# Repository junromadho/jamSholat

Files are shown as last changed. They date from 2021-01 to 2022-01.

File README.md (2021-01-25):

# jamSholat
بسم الله الرحمن الرحيم  

Project jam sholat untuk led modul P4.75 dengan menggunakan board berbasis STM32, free to share!

Note: 
Project ini didedikasikan sepenuhnya untuk keperluan amal, silakan memanfaatkan, menyebarkan, dan mengembangkannya. 
Adapun jika anda berniat untuk memanfaatkannya untuk keperluan komersial, harap sisihkan keuntungannya untuk pengembangan lebih lanjut lalu sebarkan ulang pengetahuan tersebut, semoga saja keuntungan yang didapat tidak berhenti hingga rupiah yang terkumpul. tetapi ada keuntungan akhirat yang juga ikut kita tabung.. 

Project ini terdiri dari 3 bagian hardware, software, dan tools
***
## Hardware
Mikrokontroller core yang dipakai adalah varian dari STM32 Bluepill atau Blackpill(belom tested).
Saya biasa memakai varian STM32F103C8T6 dengan papan berwarna biru. 
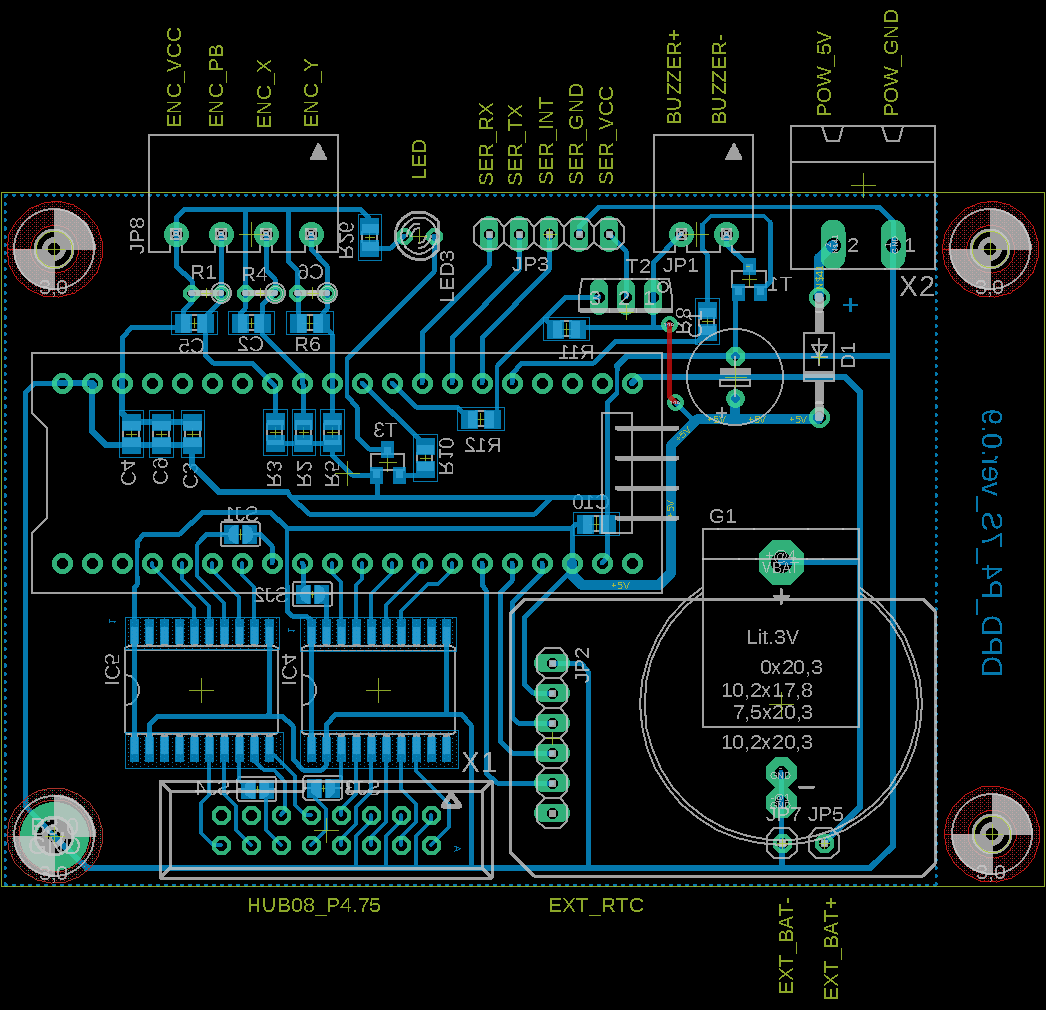
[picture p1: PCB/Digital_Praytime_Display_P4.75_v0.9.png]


Dalam kontroler board utama (file: Digital_Praytime_Display_P4.75_v0.9.brd) terdiri dari:
* soket mikrokontroler
* soket untuk HUB08
* soket baterai RTC 
* interface untuk rotary encoder
* interface untuk serial
* interface untuk buzzer
* terminal power

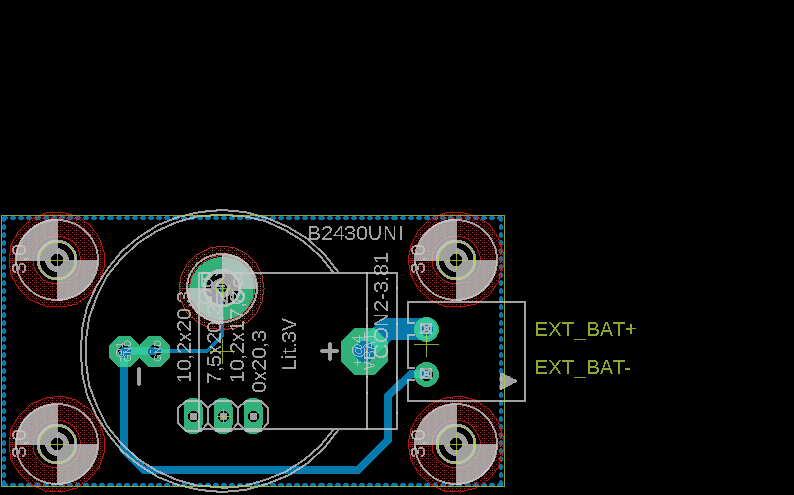
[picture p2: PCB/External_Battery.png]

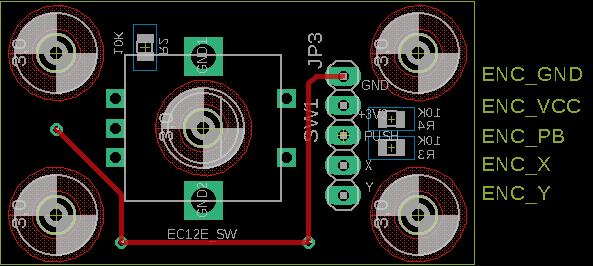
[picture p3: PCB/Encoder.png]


Pada board eksternal (file: External_Battery.brd dan Encoder.brd) terdiri dari:
* soket baterai 
* tombol rotary encoder

board eksternal berfungsi sebagai papan expansi untuk jam sholat yang menggunakan frame tertutup, sehingga board ini bisa diakses diluar 

## Software
Software yang dipakai adalah arduino dengan menggunakan tambahan *hardware* STM32 dari [Arduino STM32](https://github.com/rogerclarkmelbourne/Arduino_STM32). Untuk library saya memakai HUB08 dan RTClock.

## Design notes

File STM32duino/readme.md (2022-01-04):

Di sini semua code untuk STM32F103 arduino

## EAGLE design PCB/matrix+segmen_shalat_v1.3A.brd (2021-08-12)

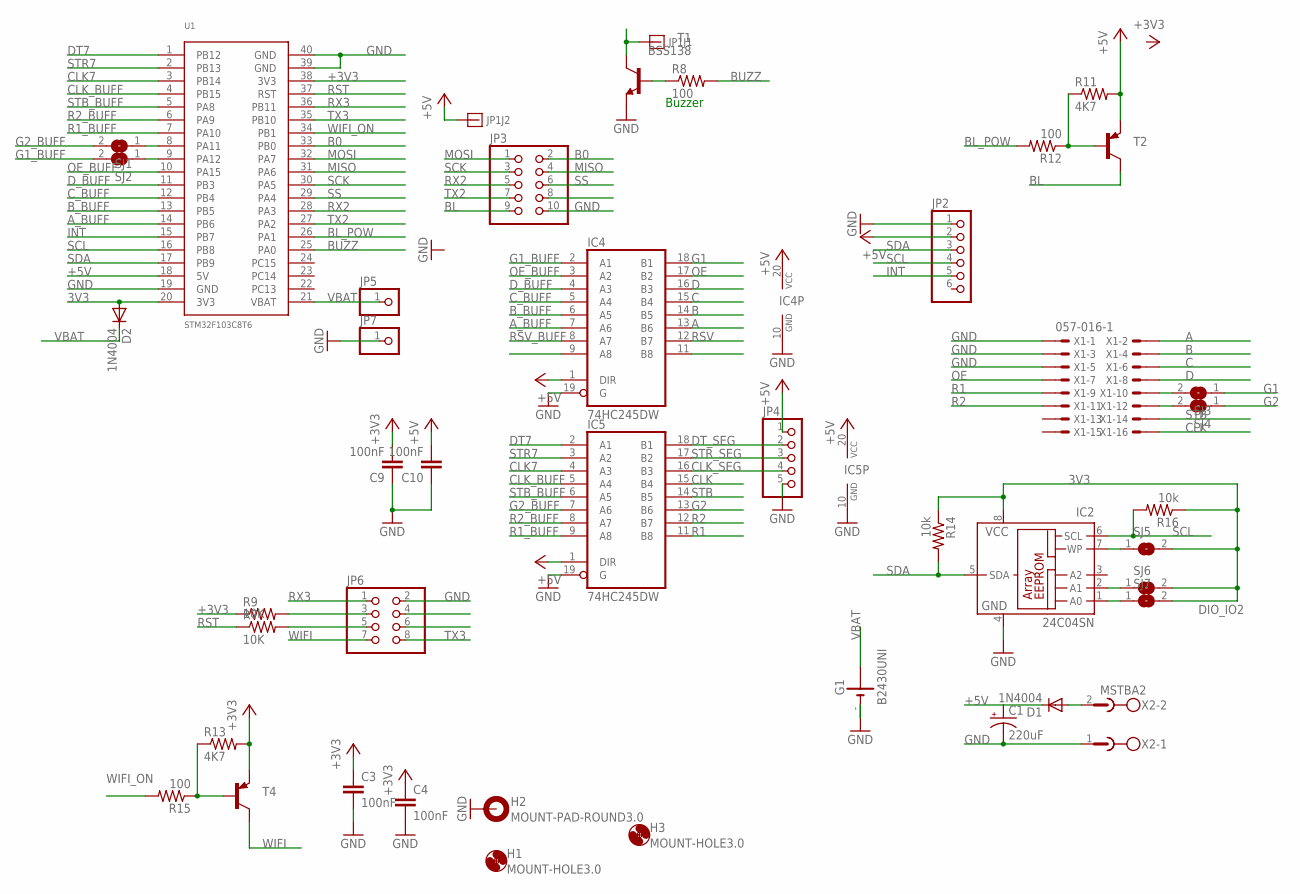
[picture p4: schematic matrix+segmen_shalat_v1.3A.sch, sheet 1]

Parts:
C1: 220uF; E3,5-8
C3, C4, C9, C10: 100nF; C0805
D1, D2: 1N4004; DO41-10
G1: B2430UNI
H1, H3: MOUNT-HOLE3.0; 3,0
H2: MOUNT-PAD-ROUND3.0; 3,0-PAD
IC2: 24C04SN; SO-08
IC4, IC5: 74HC245DW; SO20W
JP1: CON2-3.81
JP2: PINHD-1X6; 1X06
JP3: PINHD-2X5; 2X05
JP4: PINHD-1X5; 1X05
JP5, JP7: PINHD-1X1; 1X01
JP6: PINHD-2X4; 2X04
R7, R9: 10K; R0805
R8, R12, R15: 100; R0805
R11, R13: 4K7; R0805
R14, R16: 10k; R0805
SJ1, SJ2, SJ3, SJ4, SJ5, SJ6, SJ7: SJ
T1: BSS138; SOT23-BEC
T2, T4: -PNP-TO126V; TO126V
U1: STM32F103C8T6; STM32F103
X1: 057-016-1
X2: MSTBA2

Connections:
3V3: D2.A, IC2.8 (VCC), R14.1, R16.1, SJ5.2, SJ6.2, SJ7.2, U1.20 (3V3)
+3V3: C3.1, C4.1, C9.2, R9.1, R13.2, T4.1 (E), U1.38 (3V3)
+5V: C1.+, C10.2, D1.C, IC4.1 (DIR), IC4.20 (VCC), IC5.1 (DIR), IC5.20 (VCC), JP1.2, JP2.2, JP4.1, R11.2, T2.1 (E), U1.18 (5V)
A: IC4.13 (B6), X1.2
A_BUFF: IC4.7 (A6), U1.14 (PB6)
B: IC4.14 (B5), X1.4
B0: JP3.2, U1.33 (PB0)
BL: JP3.9, T2.2 (C)
BL_POW: R12.2, U1.26 (PA1)
BUZZ: R8.2, U1.25 (PA0)
B_BUFF: IC4.6 (A5), U1.13 (PB5)
C: IC4.15 (B4), X1.6
CLK: IC5.15 (B4), X1.16
CLK7: IC5.4 (A3), U1.3 (PB14)
CLK_BUFF: IC5.5 (A4), U1.4 (PB15)
CLK_SEG: IC5.16 (B3), JP4.4
C_BUFF: IC4.5 (A4), U1.12 (PB4)
D: IC4.16 (B3), X1.8
DT7: IC5.2 (A1), U1.1 (PB12)
DT_SEG: IC5.18 (B1), JP4.2
D_BUFF: IC4.4 (A3), U1.11 (PB3)
G1: IC4.18 (B1), SJ3.1
G1_BUFF: IC4.2 (A1), SJ2.2
G2: IC5.13 (B6), SJ4.1
G2_BUFF: IC5.7 (A6), SJ1.2
GND: C1.-, C3.2, C4.2, C9.1, C10.1, G1.-, G1.-@1 (-), H2.B3,0, IC2.4 (GND), IC4.10 (GND), IC4.19 (G), IC5.10 (GND), IC5.19 (G), JP2.1, JP3.10, JP4.5, JP6.2, JP7.1, T1.E, U1.19 (GND), U1.39 (GND), U1.40 (GND), X1.1, X1.3, X1.5, X2.1
INT: JP2.5, U1.15 (PB7)
MISO: JP3.4, U1.31 (PA6)
MOSI: JP3.1, U1.32 (PA7)
unnamed: R11.1, R12.1, T2.3 (B)
unnamed: R8.1, T1.B
unnamed: JP1.1, T1.C
unnamed: JP6.3, R9.2
unnamed: IC2.2 (A1), SJ6.1
unnamed: R13.1, R15.1, T4.3 (B)
unnamed: SJ1.1, U1.8 (PA11)
unnamed: SJ2.1, U1.9 (PA12)
unnamed: SJ4.2, X1.12
unnamed: SJ3.2, X1.10
unnamed: IC2.1 (A0), SJ7.1
unnamed: JP6.5, R7.2
unnamed: D1.A, X2.2
unnamed: IC2.7 (WP), SJ5.1
OE: IC4.17 (B2), X1.7
OE_BUFF: IC4.3 (A2), U1.10 (PA15)
R1: IC5.11 (B8), X1.9
R1_BUFF: IC5.9 (A8), U1.7 (PA10)
R2: IC5.12 (B7), X1.11
R2_BUFF: IC5.8 (A7), U1.6 (PA9)
RST: R7.1, U1.37 (RST)
RSV: IC4.12 (B7)
RSV_BUFF: IC4.8 (A7)
RX2: JP3.5, U1.28 (PA3)
RX3: JP6.1, U1.36 (PB11)
SCK: JP3.3, U1.30 (PA5)
SCL: IC2.6 (SCL), JP2.4, R16.2, U1.16 (PB8)
SDA: IC2.5 (SDA), JP2.3, R14.2, U1.17 (PB9)
SS: JP3.6, U1.29 (PA4)
STB: IC5.14 (B5), X1.14
STB_BUFF: IC5.6 (A5), U1.5 (PA8)
STR7: IC5.3 (A2), U1.2 (PB13)
STR_SEG: IC5.17 (B2), JP4.3
TX2: JP3.7, U1.27 (PA2)
TX3: JP6.8, U1.35 (PB10)
VBAT: D2.C, G1.+@4 (+), JP5.1, U1.21 (VBAT)
WIFI: JP6.7, T4.2 (C)
WIFI_ON: R15.2, U1.34 (PB1)

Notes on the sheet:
Buzzer

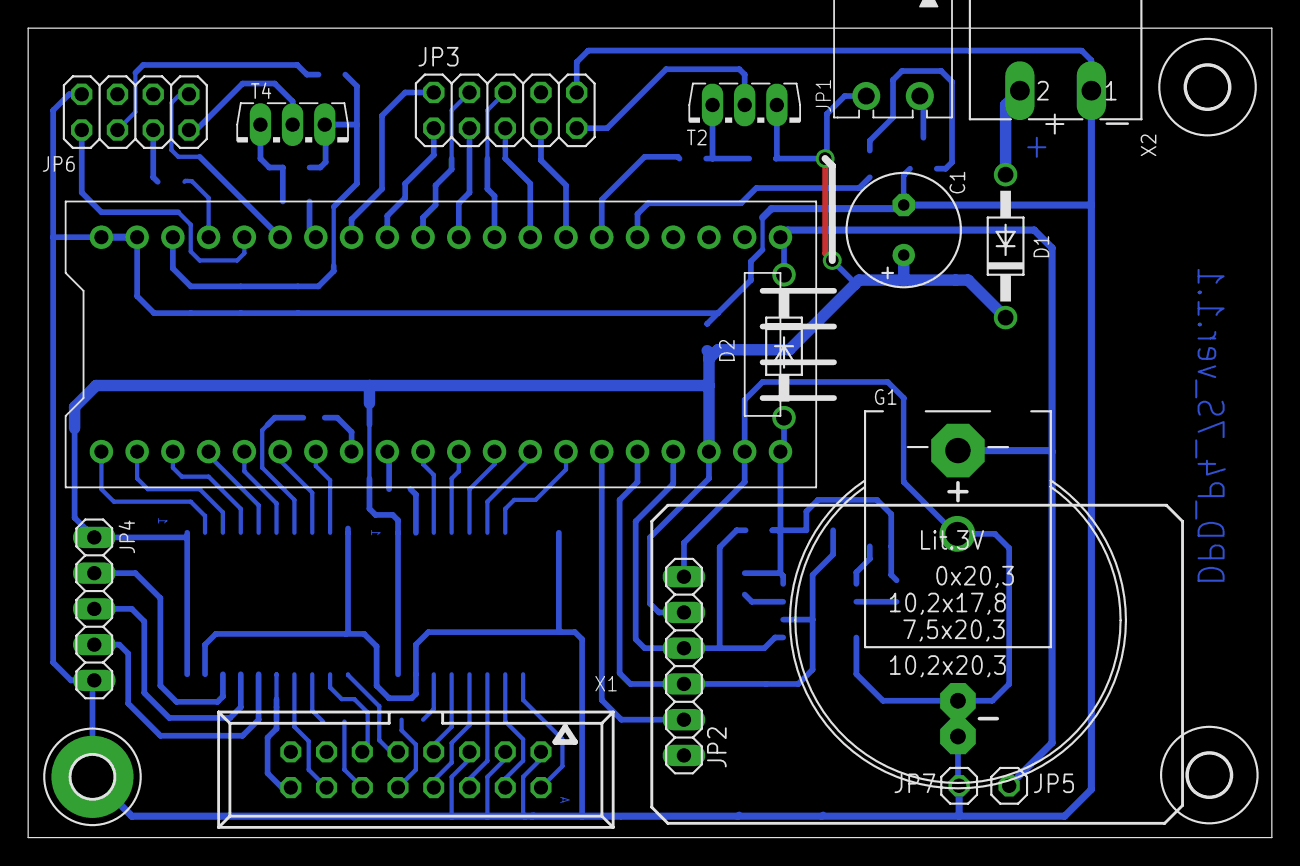
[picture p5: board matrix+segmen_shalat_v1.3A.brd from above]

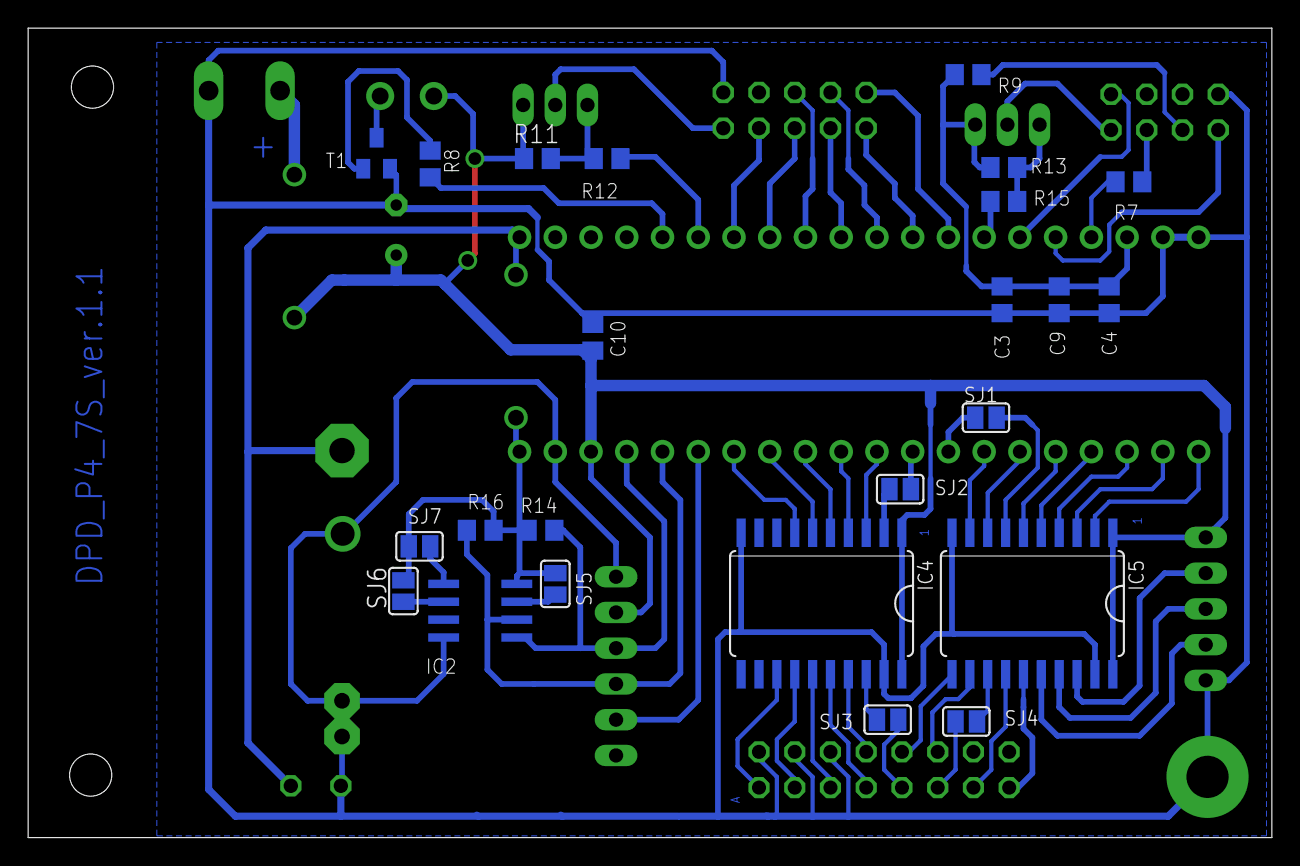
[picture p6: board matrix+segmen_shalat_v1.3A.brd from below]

Board: 2 copper layers, 88.4 x 57.5 mm, 43 parts (24 on the bottom side), 65 nets.

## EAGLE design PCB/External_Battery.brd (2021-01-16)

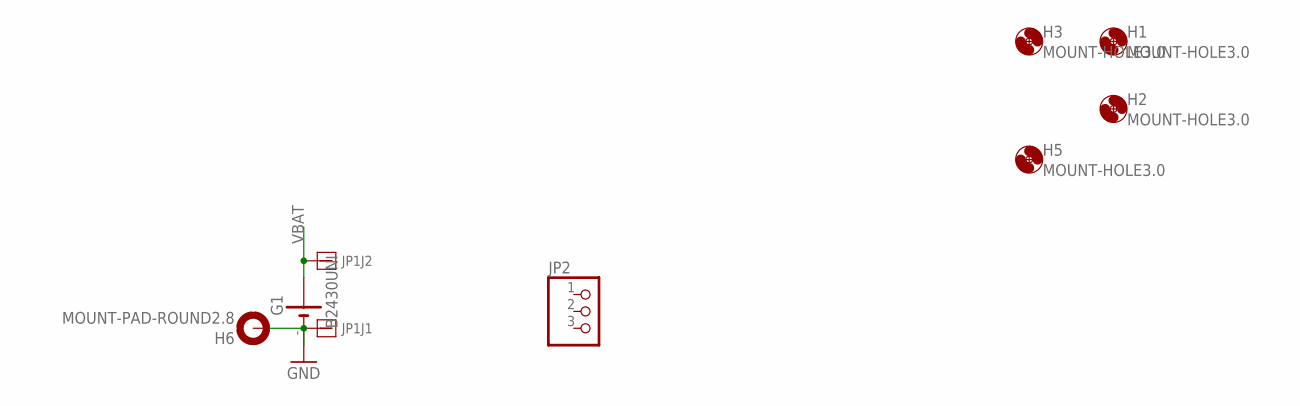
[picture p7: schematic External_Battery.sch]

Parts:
G1: B2430UNI
H1, H2, H3, H5: MOUNT-HOLE3.0; 3,0
H6: MOUNT-PAD-ROUND2.8; 2,8-PAD
JP1: CON2-3.81
JP2: PINHD-1X3; 1X03

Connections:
GND: G1.-, G1.-@1 (-), H6.B2,8, JP1.1
VBAT: G1.+@4 (+), JP1.2

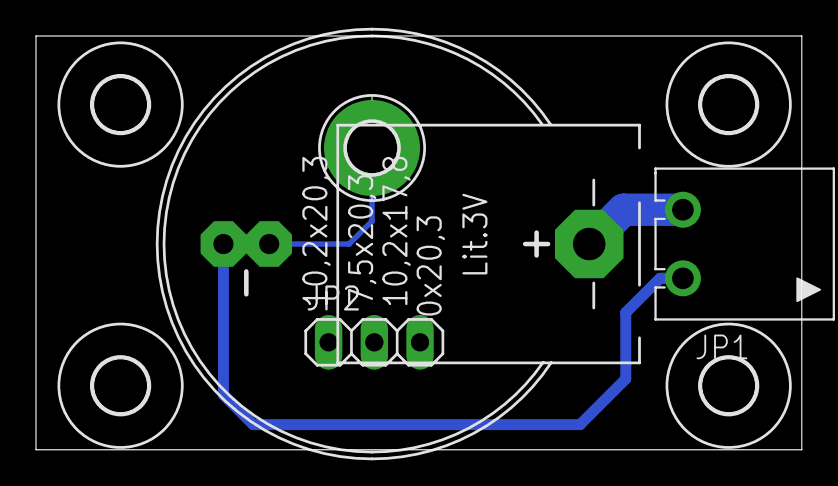
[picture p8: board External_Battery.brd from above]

Board: 2 copper layers, 42.5 x 23.0 mm, 8 parts (0 on the bottom side), 2 nets.

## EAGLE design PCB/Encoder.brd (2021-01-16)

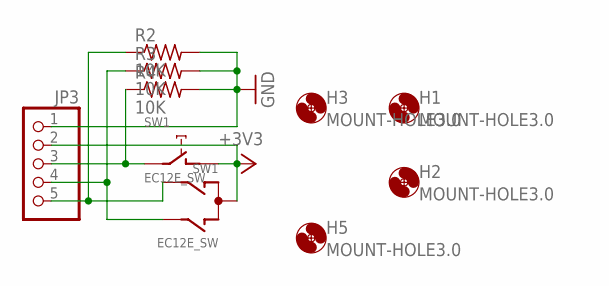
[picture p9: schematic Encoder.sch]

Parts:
H1, H2, H3, H5: MOUNT-HOLE3.0; 3,0
JP3: PINHD-1X5; 1X05
R2, R3, R4: 10K; R0805
SW1: EC12E_SW; ALPS_EC12E_SW

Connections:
+3V3: JP3.2, SW1.C, SW1.D (1)
GND: JP3.1, R2.2, R3.2, R4.2
unnamed: JP3.4, R3.1, SW1.B
unnamed: JP3.5, R2.1, SW1.A
unnamed: JP3.3, R4.1, SW1.E (2)

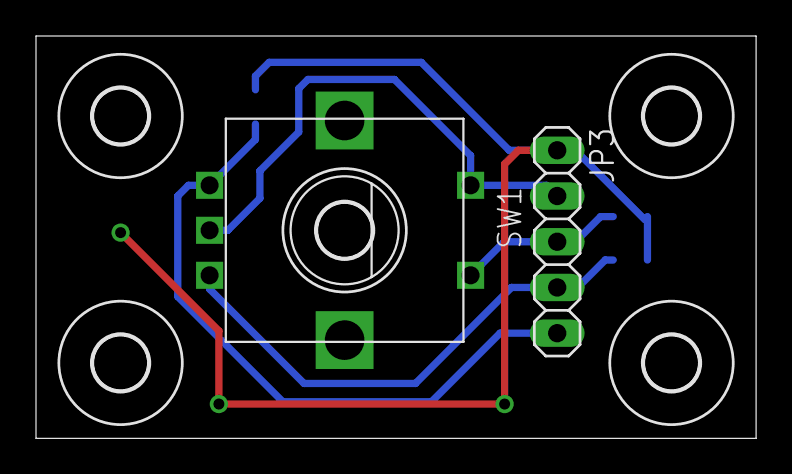
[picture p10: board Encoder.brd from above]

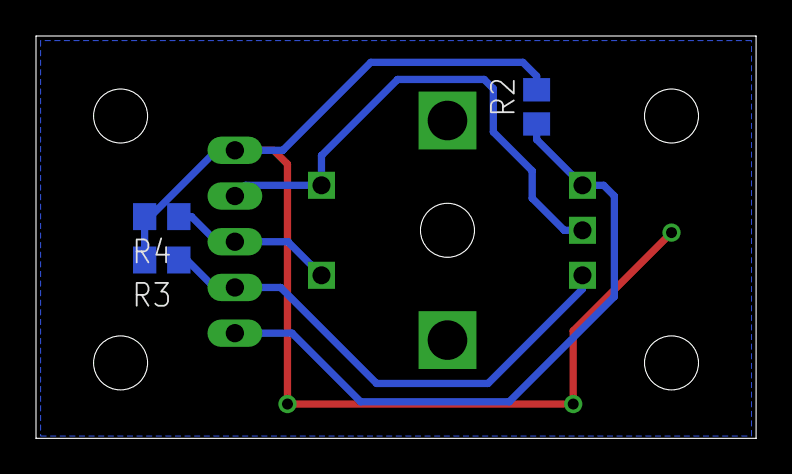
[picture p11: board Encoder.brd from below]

Board: 2 copper layers, 40.0 x 22.4 mm, 10 parts (3 on the bottom side), 5 nets.

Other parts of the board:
H4: MOUNT-HOLE3.0; 3,0

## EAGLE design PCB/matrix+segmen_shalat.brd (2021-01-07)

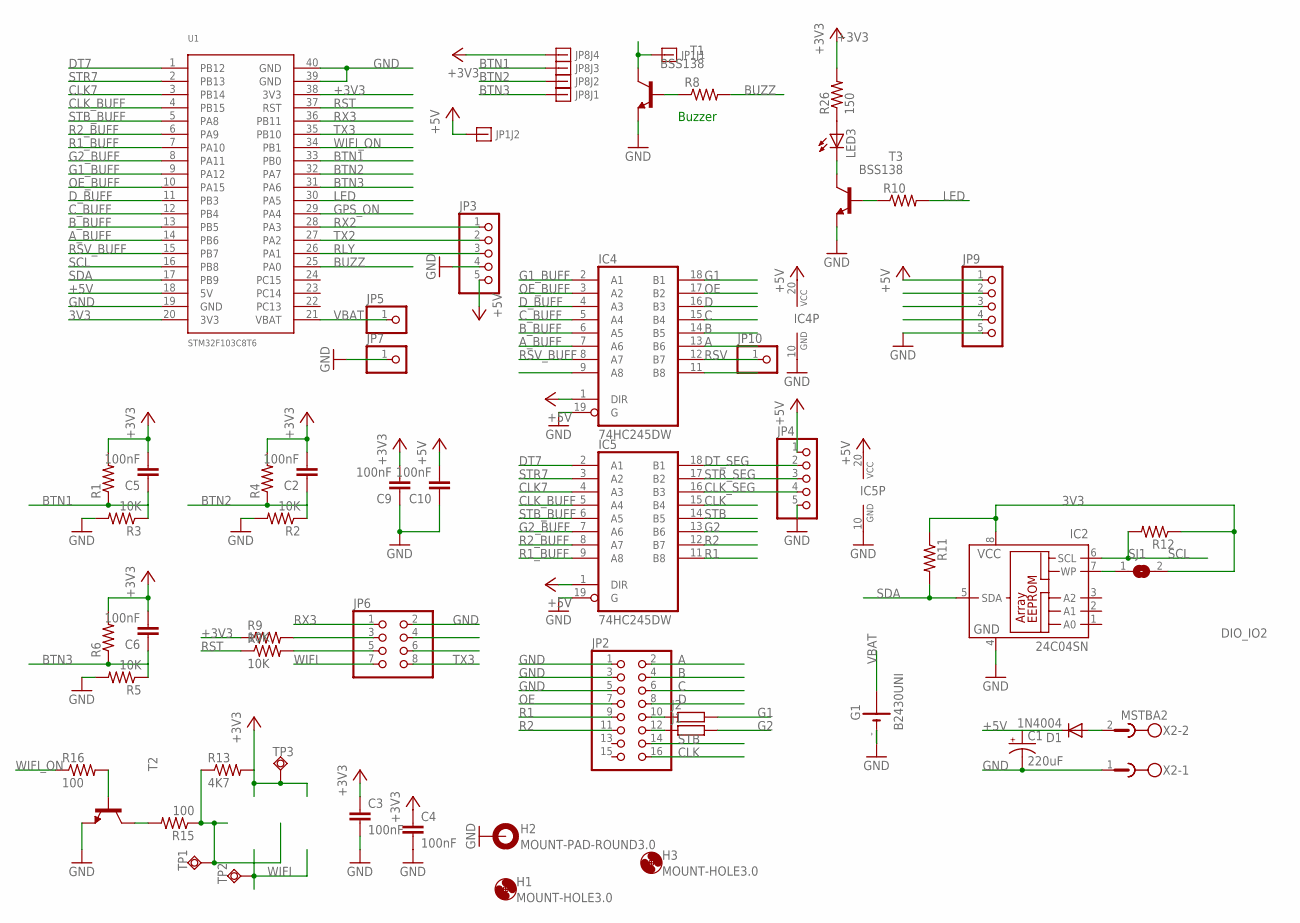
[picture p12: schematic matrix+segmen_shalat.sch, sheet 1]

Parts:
C1: 220uF; E3,5-8
C2, C3, C4, C5, C6, C9, C10: 100nF; C0805
D1: 1N4004; DO41-10
G1: B2430UNI
H1, H3: MOUNT-HOLE3.0; 3,0
H2: MOUNT-PAD-ROUND3.0; 3,0-PAD
IC2: 24C04SN; SO-08
IC4, IC5: 74HC245DW; SO20W
J1, J2: R-EU_R0402; R0402
JP1: CON2-3.81
JP2: PINHD-2X8; 2X08
JP3, JP4, JP9: PINHD-1X5; 1X05
JP5, JP7, JP10: PINHD-1X1; 1X01
JP6: PINHD-2X4; 2X04
JP8: CON4-3.81
LED3: LED3MM
R1, R4, R6: R-US_0204/2V; 0204V
R2, R3, R5: 10K; M0805
R7, R9: 10K; R0805
R8, R10, R11, R12: R-US_R0805; R0805
R13: 4K7; R0805
R15, R16: 100; R0805
R26: 150; R0805
SJ1: SJ
T1, T3: BSS138; SOT23-BEC
T2: MMBT2222ALT1-NPN-SOT23-BEC; SOT23-BEC
TP1, TP2, TP3: TPSQPAD1-13Y; P1-13Y
U1: STM32F103C8T6; STM32F103
X2: MSTBA2

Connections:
3V3: IC2.8 (VCC), R11.1, R12.1, SJ1.2, U1.20 (3V3)
+3V3: C2.2, C3.1, C4.1, C5.2, C6.2, C9.2, JP8.4, R1.2, R4.2, R6.2, R9.1, R13.2, R26.2, TP3.TP, U1.38 (3V3)
+5V: C1.+, C10.2, D1.C, IC4.1 (DIR), IC4.20 (VCC), IC5.1 (DIR), IC5.20 (VCC), JP1.2, JP3.5, JP4.1, JP9.1, U1.18 (5V)
A: IC4.13 (B6), JP2.2
A_BUFF: IC4.7 (A6), U1.14 (PB6)
B: IC4.14 (B5), JP2.4
BTN1: C5.1, JP8.3, R1.1, R3.1, U1.33 (PB0)
BTN2: C2.1, JP8.2, R2.1, R4.1, U1.32 (PA7)
BTN3: C6.1, JP8.1, R5.1, R6.1, U1.31 (PA6)
BUZZ: R8.2, U1.25 (PA0)
B_BUFF: IC4.6 (A5), U1.13 (PB5)
C: IC4.15 (B4), JP2.6
CLK: IC5.15 (B4), JP2.16
CLK7: IC5.4 (A3), U1.3 (PB14)
CLK_BUFF: IC5.5 (A4), U1.4 (PB15)
CLK_SEG: IC5.16 (B3), JP4.4
C_BUFF: IC4.5 (A4), U1.12 (PB4)
D: IC4.16 (B3), JP2.8
DT7: IC5.2 (A1), U1.1 (PB12)
DT_SEG: IC5.18 (B1), JP4.2
D_BUFF: IC4.4 (A3), U1.11 (PB3)
G1: IC4.18 (B1), J2.2
G1_BUFF: IC4.2 (A1), U1.9 (PA12)
G2: IC5.13 (B6), J1.2
G2_BUFF: IC5.7 (A6), U1.8 (PA11)
GND: C1.-, C3.2, C4.2, C9.1, C10.1, G1.-, G1.-@1 (-), H2.B3,0, IC2.4 (GND), IC4.10 (GND), IC4.19 (G), IC5.10 (GND), IC5.19 (G), JP2.1, JP2.3, JP2.5, JP3.4, JP4.5, JP6.2, JP7.1, JP9.5, R2.2, R3.2, R5.2, T1.E, T2.E, T3.E, U1.19 (GND), U1.39 (GND), U1.40 (GND), X2.1
GPS_ON: U1.29 (PA4)
LED: R10.2, U1.30 (PA5)
unnamed: J1.1, JP2.12
unnamed: LED3.K (C), T3.C
unnamed: R10.1, T3.B
unnamed: R8.1, T1.B
unnamed: JP1.1, T1.C
unnamed: JP6.3, R9.2
unnamed: J2.1, JP2.10
unnamed: R13.1, R15.1, TP1.TP
unnamed: R15.2, T2.C
unnamed: JP6.5, R7.2
unnamed: R16.2, T2.B
unnamed: LED3.A, R26.1
unnamed: D1.A, X2.2
unnamed: IC2.7 (WP), SJ1.1
OE: IC4.17 (B2), JP2.7
OE_BUFF: IC4.3 (A2), U1.10 (PA15)
R1: IC5.11 (B8), JP2.9
R1_BUFF: IC5.9 (A8), U1.7 (PA10)
R2: IC5.12 (B7), JP2.11
R2_BUFF: IC5.8 (A7), U1.6 (PA9)
RLY: JP3.3, U1.26 (PA1)
RST: R7.1, U1.37 (RST)
RSV: IC4.12 (B7), JP10.1
RSV_BUFF: IC4.8 (A7), U1.15 (PB7)
RX2: JP3.1, U1.28 (PA3)
RX3: JP6.1, U1.36 (PB11)
SCL: IC2.6 (SCL), R12.2, U1.16 (PB8)
SDA: IC2.5 (SDA), R11.2, U1.17 (PB9)
STB: IC5.14 (B5), JP2.14
STB_BUFF: IC5.6 (A5), U1.5 (PA8)
STR7: IC5.3 (A2), U1.2 (PB13)
STR_SEG: IC5.17 (B2), JP4.3
TX2: JP3.2, U1.27 (PA2)
TX3: JP6.8, U1.35 (PB10)
VBAT: G1.+@4 (+), JP5.1, U1.21 (VBAT)
WIFI: JP6.7, TP2.TP
WIFI_ON: R16.1, U1.34 (PB1)

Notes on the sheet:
Buzzer

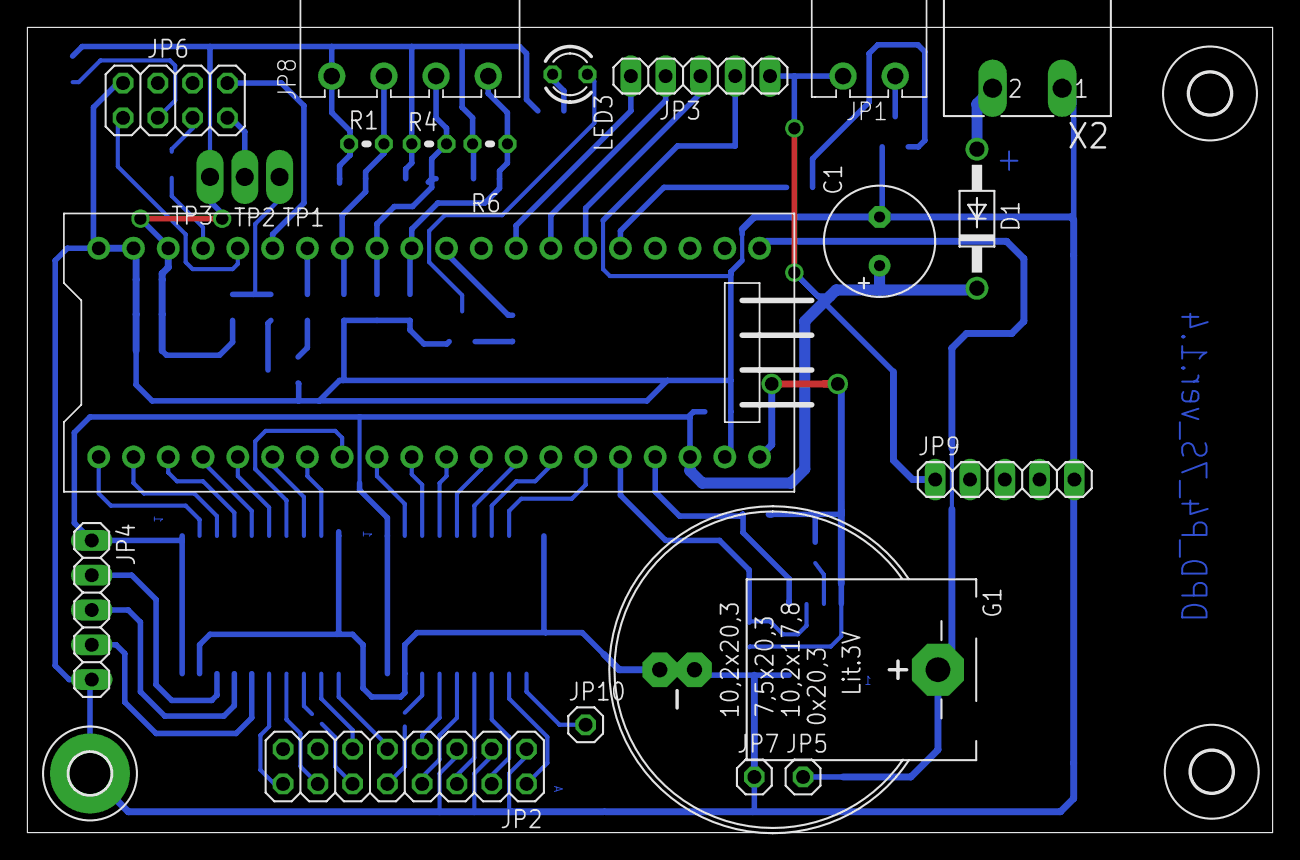
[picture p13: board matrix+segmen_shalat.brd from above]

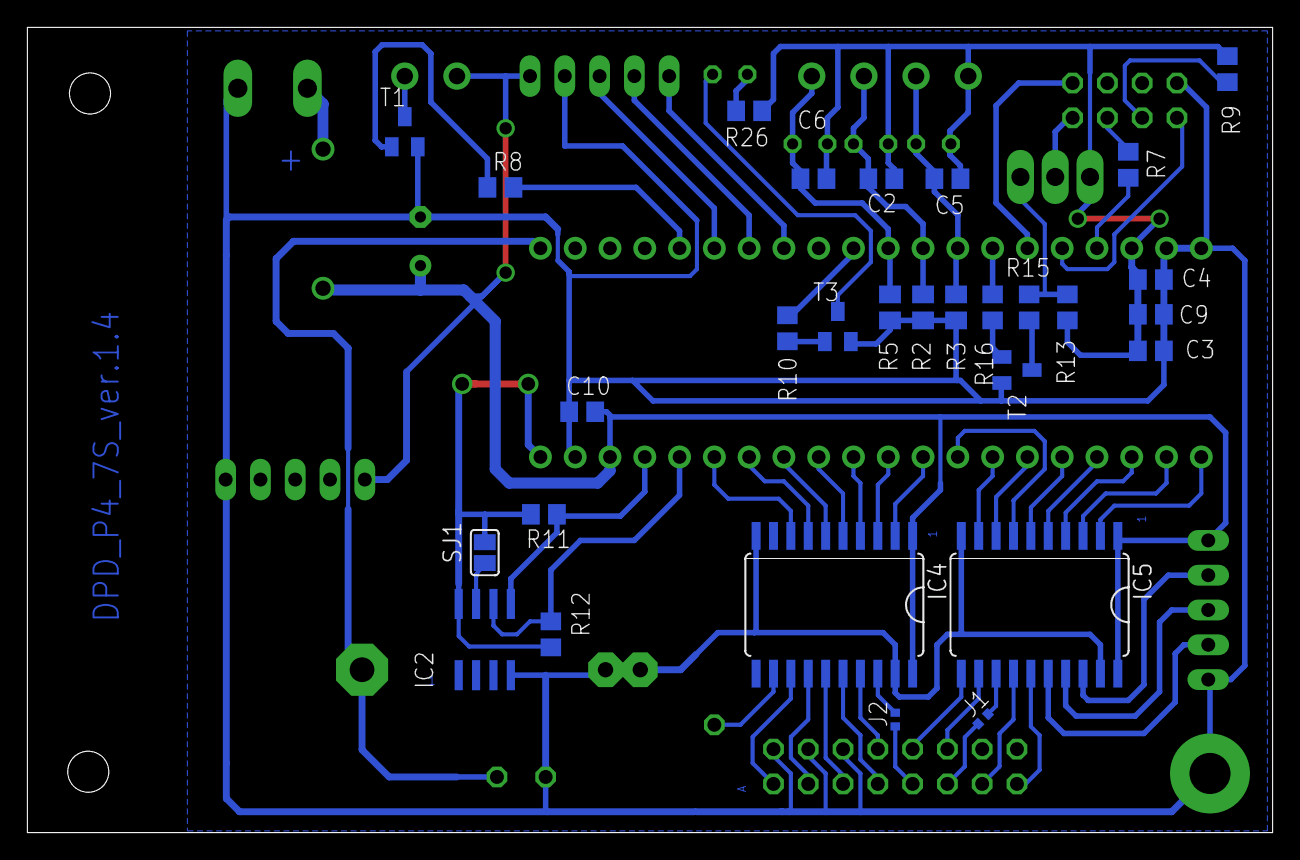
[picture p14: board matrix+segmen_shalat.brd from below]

Board: 2 copper layers, 90.9 x 58.8 mm, 54 parts (29 on the bottom side), 64 nets.

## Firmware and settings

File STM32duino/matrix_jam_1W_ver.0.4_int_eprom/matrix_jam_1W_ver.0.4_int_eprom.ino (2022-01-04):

/*
  بسم الله الرحمن الرحيم *
*/

// peer waktu sholat jumat

#include <HUB08.h>
#include "RTClock.h"
#include <fonts/font5x7.h>
#include <fonts/LinLibertine32.h>
#include <EEPROM.h>

#define USART Serial3
/////////////////////////////////// Inisiasi DMD pin ////////////////////////////////////
///
///
///
#define DISPLAYS_ACROSS 1
#define DISPLAYS_DOWN 1

DMD matrix(DISPLAYS_ACROSS, DISPLAYS_DOWN);
RTClock rt(RTCSEL_LSE);

/**************************************** Begin Declaration ***************************************/

//////////////// Coordinate Variable//////////////////
//float Longitude = 108.443667, Latitude = -6.660453; //Cirebon
//float Longitude = 107.561833, Latitude = -6.931706; //Bandung
//float Longitude = 111.978716, Latitude = -7.801222; //Kediri
float Longitude, Latitude;
/////////////////////////////////////////// Clock /////////////////////////////////////////////////
///
///

#define LatAddr  10
#define LongAddr 26
#define SubAddr  42 
#define DzuAddr  43 
#define AshAddr  44 
#define MagAddr  45 
#define IsyAddr  46 
#define BrgAddr  47 
#define SpdAddr  48 
#define MjdAddr  50 

/////////////////////////////////// Inisiasi Buzzer pin ////////////////////////////////////
///
///

#define buzz_pin PA0
//#define ind_pin PC13
#define wifiPowPin PB1

#define pinBuzz 0x0001
#define Buzz(BIT)      (BIT) ? (GPIOA->regs->BSRR = pinBuzz)   : (GPIOA->regs->BRR = pinBuzz)

uint16_t buzzTone[4] = {0x03, 0x33, 0x9993, 0x3f};
bool buzzStat = false;
int elapsedBuzz = 0;
uint8_t Tone = 0;

bool offlineFlag = false;
int offlineCount = 420;   // hitungan modul wifi dimatikan (dalam detik)
int closePrayTime = 180;  //2 x 60s  waktu menjelang sholat  (dalam detik)
int jumatTime = 1200, closeJumat = 300; //1200; //20 x 60   (dalam detik) 1200 300
const uint8_t jedaWaktuSholat = 6; //tampilan save mode saat sholat (dalam menit)
//////////////////////////////////////// RTC ////////////////////////////////////////////////
///
///
///

struct tm * waktu;
time_t ssec;
uint32_t WIB = 25200, epoch;
unsigned char Day;
int cur_tstamp;

int sub_tstamp, syu_tstamp, dhu_tstamp, dzu_tstamp, ash_tstamp, mag_tstamp, isy_tstamp;

//////////////////////////////////////  Flag Waktu Sholat ////////////////////////////////////////////////
///
///
///


int8_t iqoSub, iqoDzu, iqoAsh, iqoMag, iqoIsy;
int iqoSubTimeout, iqoDzuTimeout, iqoAshTimeout, iqoMagTimeout, iqoIsyTimeout;
//bool inTime = false;

//bool sholaTimeFlag = false;
typedef enum shola {
  idle = 0, subuh, syuruq, dhuha, dzuhur, ashar, maghrib, isya
};
shola sholat = idle;
typedef enum statusSholat {
  luarWaktu = 0, masukWaktu, dalamWaktu
};
statusSholat prayState, tmpPrayState;


uint8_t tmp_jam, tmp_menit;
int tock;
bool flick = false;
bool clearMain = false;
bool saveMode = false;

////////////////////////////// Menu Variable ///////////////////////////////////
///
///
///

//bool mainDisplay = true;
bool mainMenu = true;
uint8_t brightVal, textSpeed;
char latBuff[16], longBuff[16];
//////////////////////////////////Buffer Processing /////////////////////////////////////
//
//
String inputString;
char timeBuff[16];  // YYYYMMDDHHmmSS

///////////////////////////////// Display variable ///////////////////////////////////////
///
///
///

typedef enum diplayTopSeq {
  praySeq = 0, dateSeq, mosSeq, iqoSeq, flickSeq, jumatMes
};
int startSlowPix = 0, endSlowPix = 0;
bool drawBotFlag = false, drawTopFlag = false , drawMenu = false, clearTop = false;//,  drawLeftFlag = true; //clearAll = false,
diplayTopSeq topRowSeq = mosSeq;
int topCursorX;
int randX, randY;
int topPixLimit[7];
int topShiftPixel[7] = {64, 64, 64, 64, 64, 64};
uint8_t messageLenght[6], mesDuration[6] = {6, 8, 8, 7, 9, 8};
char infoText[6][128];
char outputChar[32];

char NAMA_MASJID[128] = "Masjid Al Hidayah, Lemah Hegar Kiaracondong - Bandung";
#define TEXT_IQOMAH   "Iqomah"
//char TEXT_PESAN1[128] = "Rapat dan luruskan shaf karena rapat dan lurus shaf termasuk dari kesempurnaan sholat";
#define TEXT_PESAN2   "Mohon non-aktifkan handphone di dalam masjid. Dilarang berbicara saat khotib berkhutbah"

/************************************************** End of Declaration ***********************************************/


void setup() {
  bool checkUID = false;
  //  afio_cfg_debug_ports(AFIO_DEBUG_SW_ONLY);

  pinMode(wifiPowPin, OUTPUT);
  digitalWrite(wifiPowPin, HIGH);
  delay(100);
  digitalWrite(wifiPowPin, LOW);
  pinMode(buzz_pin, OUTPUT);
  USART.begin(115200);

  EEPROM.PageBase0 = 0x801F000;
  EEPROM.PageBase1 = 0x801F800;
  EEPROM.PageSize  = 0x200;
  EEPROM.init();

  delay(50);
  loadRom();
  if ((brightVal < 1) || (brightVal > 20)) {
    brightVal = 6;
    EEPROM.write(BrgAddr, (uint16_t) brightVal);
  }
  if ((textSpeed < 1) || (textSpeed > 20)) {
    textSpeed = 14;
    EEPROM.write(SpdAddr, (uint16_t) textSpeed);
  }
  //  checkUID = decrypt();
  //  while (!checkUID) {
  //    wR1(1);
  //    wD(1);
  //    wCLK(1);
  //    wCLK(0);
  //  }

  mesDuration[mosSeq] = 22 - textSpeed;
  mesDuration[dateSeq] = 22 - textSpeed;
  mesDuration[praySeq] = 22 - textSpeed;
  mesDuration[jumatMes] = 22 - textSpeed;
  ssec = WIB + rt.getTime();
  if (ssec < 1553037557) {
    rt.setTime(1553037557);
    ssec = 1553037557;
  }
  waktu = localtime (&ssec);

  countShalat();
  Timer2.setChannel1Mode(TIMER_OUTPUTCOMPARE);
  Timer2.setPeriod(20); // in microseconds
  Timer2.setCompare1(1);      // overflow might be small
  Timer2.attachCompare1Interrupt(scanHandler);

  rt.attachSecondsInterrupt(tick);
  delay(500);
  matrix.clearScreen(true);

  drawBottom();
  topBufferProc();
  customBufferProc();
  enaBuzz(1, 0);
}

void loop() {
  switch (offlineFlag) {
    case false:
      if (USART.available() > 0) {
        Timer2.pause();
        // get the new byte:
        char inChar = (char) USART.read();
        if ((inChar >= 32) && (inChar < 127))
          inputString += inChar;
        if (inChar == '\n') {
          if (inputString.startsWith("T,") == true) {
            rt.detachSecondsInterrupt();
            inputString.remove(0, 2);
            inputString.toCharArray(timeBuff, sizeof(inputString));
            ssec = strtoul(timeBuff, NULL, 0);
            rt.setTime(ssec);
            clearMain = true;
            waktu = localtime (&ssec);

            checkPrayTime();
            drawBottom();
            prayInfoBuffer();
            customBufferProc();
            topBufferProc();
            enaBuzz(1, 0);
            //        USART.println(ssec);
            rt.attachSecondsInterrupt(tick);
          } else if (inputString.startsWith("I,") == true) {
            inputString.remove(0, 2);
            iqoSub = inputString.toInt();
            if (iqoSub > 25)iqoSub = 25;
            EEPROM.write(SubAddr, (uint16_t) iqoSub);
            inputString.remove(0, inputString.indexOf(',') + 1);

            iqoDzu = inputString.toInt();
            if (iqoDzu > 15)iqoDzu = 15;
            EEPROM.write( DzuAddr, (uint16_t) iqoDzu);
            inputString.remove(0, inputString.indexOf(',') + 1);

            iqoAsh = inputString.toInt();
            if (iqoAsh > 15)iqoAsh = 15;
            EEPROM.write(AshAddr, (uint16_t) iqoAsh);
            inputString.remove(0, inputString.indexOf(',') + 1);

            iqoMag = inputString.toInt();
            if (iqoMag > 15)iqoMag = 15;
            EEPROM.write(MagAddr, (uint16_t) iqoMag);
            inputString.remove(0, inputString.indexOf(',') + 1);

            iqoIsy = inputString.toInt();
            if (iqoIsy > 15)iqoIsy = 15;
            EEPROM.write(IsyAddr, (uint16_t) iqoIsy);
            prayInfoBuffer();
            enaBuzz(1, 0);
            //outBuff();
          } else if (inputString.startsWith("S,") == true) {
            inputString.remove(0, 2);
            textSpeed = inputString.toInt();
            mesDuration[mosSeq] = 22 - textSpeed;
            mesDuration[dateSeq] = 22 - textSpeed;
            mesDuration[praySeq] = 22 - textSpeed;
            EEPROM.write(SpdAddr,  (uint16_t) textSpeed);
            enaBuzz(1, 0);
            //            USART.println(textSpeed);
            //outBuff();
          } else if (inputString.startsWith("LL,") == true) {
            memset(latBuff, '\0', 16);
            inputString.remove(0, 3);
            inputString.toCharArray(latBuff, inputString.indexOf(',') + 1);
            Latitude = atof(latBuff);
            for (int idx = 0; idx < strlen(latBuff) ; idx++) {
              EEPROM.write(LatAddr + idx, (uint16_t) latBuff[idx]);
              USART.print(latBuff[idx]);
            }
//            USART.print("\nlat in buff: ");
//            USART.println(latBuff);
//            USART.print("lat in float: ");
//            USART.println(Latitude, 5);
            inputString.remove(0, inputString.indexOf(',') + 1);
            memset(longBuff, '\0', 16);
            inputString.toCharArray(longBuff, inputString.length() + 1);
            for (int idx = 0; idx < strlen(longBuff) ; idx++) {
              EEPROM.write(LongAddr + idx, (uint16_t) longBuff[idx]);
              USART.print(longBuff[idx]);
            }
            Longitude = atof(longBuff);
//            USART.print("\nlong in buff: ");
//            USART.println(longBuff);
//            USART.print("long in float: ");
//            USART.println(Longitude, 5);
            enaBuzz(1, 0);
            //outBuff();
          } else if (inputString.startsWith("MJ,") == true) {
            inputString.remove(0, 3);
            memset(NAMA_MASJID, '\0', 80);
            inputString.toCharArray(NAMA_MASJID, inputString.length() + 1);
            for (int idx = 0; idx < 80 ; idx++) {
              EEPROM.write(MjdAddr + idx, (uint16_t) NAMA_MASJID[idx]);
            }
//            USART.print("masjid: ");
//            USART.println(NAMA_MASJID);
            enaBuzz(1, 0);
          } else if (inputString.startsWith("WOFF") == true) {
            //            digitalWrite(wifiPowPin, HIGH);
          } else if (inputString.startsWith("B,") == true) {
            inputString.remove(0, 2);
            brightVal = inputString.toInt();
            EEPROM.write(BrgAddr,  (uint16_t) brightVal);
            enaBuzz(1, 0);
            //            USART.println(brightVal);

          } else if (inputString.startsWith("reboot") == true) {
            nvic_sys_reset();
          } else if (inputString.startsWith("load") == true) {
            loadRom();
          } else if (inputString.startsWith("?") == true) {
          }
          inputString = "";
        }
        Timer2.refresh();
        Timer2.resume();
      }
      break;
  }

  if (clearMain) {
    clearMain = false;
    matrix.clearScreen(true);
  }

  if (drawBotFlag) {
    drawBotFlag = false;
    dateBuff();
    drawBottom();
  }
  if (!saveMode) {
    if (drawTopFlag) {
      drawTopFlag = false;
      drawTop();
    }
  }
}

void tick() {
  switch (offlineFlag) {
    case false:
      offlineCount--;
      OBLed(1);
      if (offlineCount <= 0) {
        offlineFlag = true;
        digitalWrite(wifiPowPin, HIGH);
      }
      break;
  }

  flick = true;
  ssec = WIB + rt.getTime();
  waktu = localtime (&ssec);
  cur_tstamp = (int)(ssec % 86400);

  if (Day != waktu->tm_mday) {
    countShalat();
    topBufferProc();
    customBufferProc();
  }
  if (tmp_jam != (uint8_t) waktu->tm_hour) {
    hourToBuff();
  } else if (tmp_menit != (uint8_t) waktu->tm_min) {
    if (saveMode) {
      randX = random(0, 34);
      randY = random(0, 25);
      clearMain = true;
    }
    minToBuff();
  }
  drawBotFlag = true;

  tmp_jam = (uint8_t) waktu->tm_hour;
  tmp_menit = (uint8_t) waktu->tm_min;
  //  if (sholat != idle) {
  checkPrayTime();

  //  }
  //  USART.println("tick");
}

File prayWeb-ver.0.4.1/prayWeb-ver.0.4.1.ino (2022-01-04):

/*
   ESP8266 (NodeMCU) Handling Web form data basic example
   <a href="https://circuits4you.com">https://circuits4you.com</a>
*/
#include <ESP8266WiFi.h>
#include <ESPAsyncTCP.h>
#include <ESPAsyncWebServer.h>
#include <FS.h>
//#include "WiFiTerm.h"
//#include <WiFiClient.h>
//#include <ESP8266WebServer.h>
#include <ESP8266mDNS.h>
#include <WiFiUdp.h>
#include <Ticker.h>
//#include <Effortless_SPIFFS.h>

#define VERSION "ver. 0.4"
char MASJID[48];
char ALAMAT[128];
char LATITUDE[16];// = "-6.931706";
char LONGITUDE[16];// = "107.561833";
char BRIGHTVAL[2];
char SPEEDVAL[2];
//kediri -7.8140281,111.9780112
typedef enum idx {
  spiWrt = 0, vers, mosq, madd, lati, lont, brig, spee, last
};
idx spiIndex;

AsyncWebServer server(80);
String message, buff;
//const char* PARAM_MESSAGE = "message";

//SSID and Password of your WiFi router
//char* ssid = "Androido";
//char* password = "tkvo8562";
char ssid[24] = "JamSholat_";
char* password = "12345678";
char lastTime[24];

IPAddress local_ip(192, 168, 0, 1);
IPAddress gateway(192, 168, 0, 1);
IPAddress subnet(255, 255, 255, 0);

//IPAddress remot(192, 168, 43, 236);
IPAddress remot(192, 168, 0, 2);
WiFiUDP Udp;
unsigned int localPort = 8888;      // local port to listen on
unsigned int remotPort = 1230;
//char packetBuffer[UDP_TX_PACKET_MAX_SIZE + 1]; //buffer to hold incoming packet,
//char  ReplyBuffer[] = "Mulai";       // a string to send back
char inputChar[512];
String inputString = "", termBuff;

Ticker blinker;
#define maxLifeTick 360
File f;
//eSPIFFS fileSystem;

//==============================================================
//                  SETUP
//==============================================================
void setup(void) {

  char buffMac[3];
  WiFi.mode(WIFI_OFF);
  Serial.begin(115200);
  //  if (!SPIFFS.begin()) {
  //    //    Serial.println("An Error has occurred while mounting SPIFFS");
  //    return;
  //  }
  SPIFFS.begin();
  loadRom();
  delay(1000);

  //  eSPIFFS fileSystem;
  uint8_t macAddr[6];
  WiFi.macAddress(macAddr);
  itoa (macAddr[3], buffMac, 16);
  strcat(ssid, buffMac);
  itoa (macAddr[4], buffMac, 16);
  strcat(ssid, buffMac);
  itoa (macAddr[5], buffMac, 16);
  strcat(ssid, buffMac);


  WiFi.softAPConfig (local_ip, gateway, subnet);
  WiFi.softAP(ssid, password, 1, false, 1);
  /*
      WiFi.begin(ssid, password);     //Connect to your WiFi router
      Serial.print("\nssid: "); Serial.println(ssid);
    //   Wait for connection
      while (WiFi.status() != WL_CONNECTED) {
        delay(500);
        Serial.print(".");
      }

    If connection successful show IP address in serial monitor
      Serial.println("");
      Serial.print("Connected to ");
      Serial.println("WiFi");
      Serial.print("IP address: ");
      Serial.println(WiFi.localIP());  //IP address assigned to your ESP
  */
  if (!MDNS.begin("jamsholat")) {
    //    Serial.println("Error setting up MDNS responder!");
    //    while (1) {
    //      delay(1000);
    //    }
  }

  // Route for root / web page
  server.on("/", HTTP_GET, [](AsyncWebServerRequest * request) {
    request->send(SPIFFS, "/index.html", String(), false, processor);
    //    Serial.write(0x02);
    Serial.print("US");
    Serial.println();
    //    Serial.write(0x03);
  });
  server.on("/mosque.png", HTTP_GET, [](AsyncWebServerRequest * request) {
    request->send(SPIFFS, "/mosque.png", "image/png");
  });
  server.on("/style.css", HTTP_GET, [](AsyncWebServerRequest * request) {
    request->send(SPIFFS, "/style.css", "text/css");
  });

  server.on("/masjid", HTTP_GET, [](AsyncWebServerRequest * request) {
    request->send(SPIFFS, "/wifi.html", String(), false, processor);
  });

  server.on("/mosque_conf", HTTP_POST, [](AsyncWebServerRequest * request) {
    if (request->hasParam("masjid", true)) {
      message = request->getParam("masjid", true)->value();
      message.toCharArray(MASJID, 48);
      writeROM(MASJID, mosq);
      message += ", ";
    }
    //    Serial.println(MASJID);
    if (request->hasParam("alamat", true)) {
      buff = request->getParam("alamat", true)->value();
      message += buff;
      buff.toCharArray(ALAMAT, 128);
      writeROM(ALAMAT, madd);
    }
    //    Serial.println(ALAMAT);
    Serial.print("MJ,");
    Serial.print(message);
    Serial.println();
    request->send(SPIFFS, "/wifi.html", String(), false, processor);
  });

  server.on("/coordinate_conf", HTTP_POST, [](AsyncWebServerRequest * request) {
    if (request->hasParam("lat", true)) {
      message = request->getParam("lat", true)->value();
      message.toCharArray(LATITUDE, sizeof(message));
      writeROM(LATITUDE, lati);
      message += ",";
    }
    //    double lat = atof(LATITUDE);
    //    Serial.println(lat,5);
    if (request->hasParam("long", true)) {
      buff = request->getParam("long", true)->value();
      message += buff;
      buff.toCharArray(LONGITUDE, sizeof(buff));
      writeROM(LONGITUDE, lont);
    }
    //    double lon = atof(LONGITUDE);
    //    Serial.println(lon,5);
    Serial.print("LL,");
    Serial.print(message);
    Serial.println();
    request->send(SPIFFS, "/wifi.html", String(), false, processor);
  });

  server.on("/gps_page", HTTP_POST, [](AsyncWebServerRequest * request) {
    Serial.println("gps");
    request->send(SPIFFS, "/wifi.html", String(), false, processor);
  });

  server.on("/reboot", HTTP_GET, [](AsyncWebServerRequest * request) {
    Serial.println("reboot");
    request->send(SPIFFS, "/index.html", String(), false, processor);
  });

  server.on("/sync_page", HTTP_POST, [](AsyncWebServerRequest * request) {
    if (request->hasParam("date", true)) {
      message = request->getParam("date", true)->value();
    } else {
      //      message = "No message sent";
    }
    if (request->hasParam("fdate", true)) {
      buff = request->getParam("fdate", true)->value();
      buff.toCharArray(lastTime, buff.length() + 1);
      writeROM(lastTime, last);
    }
    //        Serial.write(0x02);
    Serial.print("T,");
    Serial.print(message);
    Serial.println();
    //        Serial.println(lastTime);
    //    Serial.write(0x03);

    request->send(SPIFFS, "/index.html", String(), false, processor);
  });

  server.on("/bright_page", HTTP_POST, [](AsyncWebServerRequest * request) {
    if (request->hasParam("bright", true)) {
      buff = request->getParam("bright", true)->value();
      buff.toCharArray(BRIGHTVAL, sizeof(buff));
      writeROM(BRIGHTVAL, brig );
    } else {
      //      message = "No message sent";
    }
    //    Serial.write(0x02);
    Serial.print("B,");
    Serial.print(buff);
    Serial.println();
    //    Serial.write(0x03);

    request->send(SPIFFS, "/index.html", String(), false, processor);
  });
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

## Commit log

2021-01-07 PCB untuk versi 1.4, perubahan code pin harus disesuaikan
    [matrix+segmen_shalat.brd, matrix+segmen_shalat.sch]
2021-01-16 add some code and pcb
    [Bat.brd, Bat.sch, Dial.brd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]
2021-01-25 Melengkapi resource
    [Encoder.brd, Encoder.sch, External_Battery.brd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]
2021-08-12 layout PCB utk jam sholat p4.75 ver.1.3a
    [matrix+segmen_shalat_v1.3A.brd, matrix+segmen_shalat_v1.3A.sch]
